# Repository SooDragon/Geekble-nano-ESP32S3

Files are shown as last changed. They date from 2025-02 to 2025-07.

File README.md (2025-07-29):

Geekble nano ESP32-S3
=============
Geekble nano ESP32-S3 문서에 오신것을 환영합니다

아두이노 IDE에서 쉽게 사용할 수 있는 Geekble nano를 통해 WiFi, Bluetooth, USB HID 기능을 여러분의 프로젝트에 구현할 수 있습니다

Geekble nano 핀맵
-------------
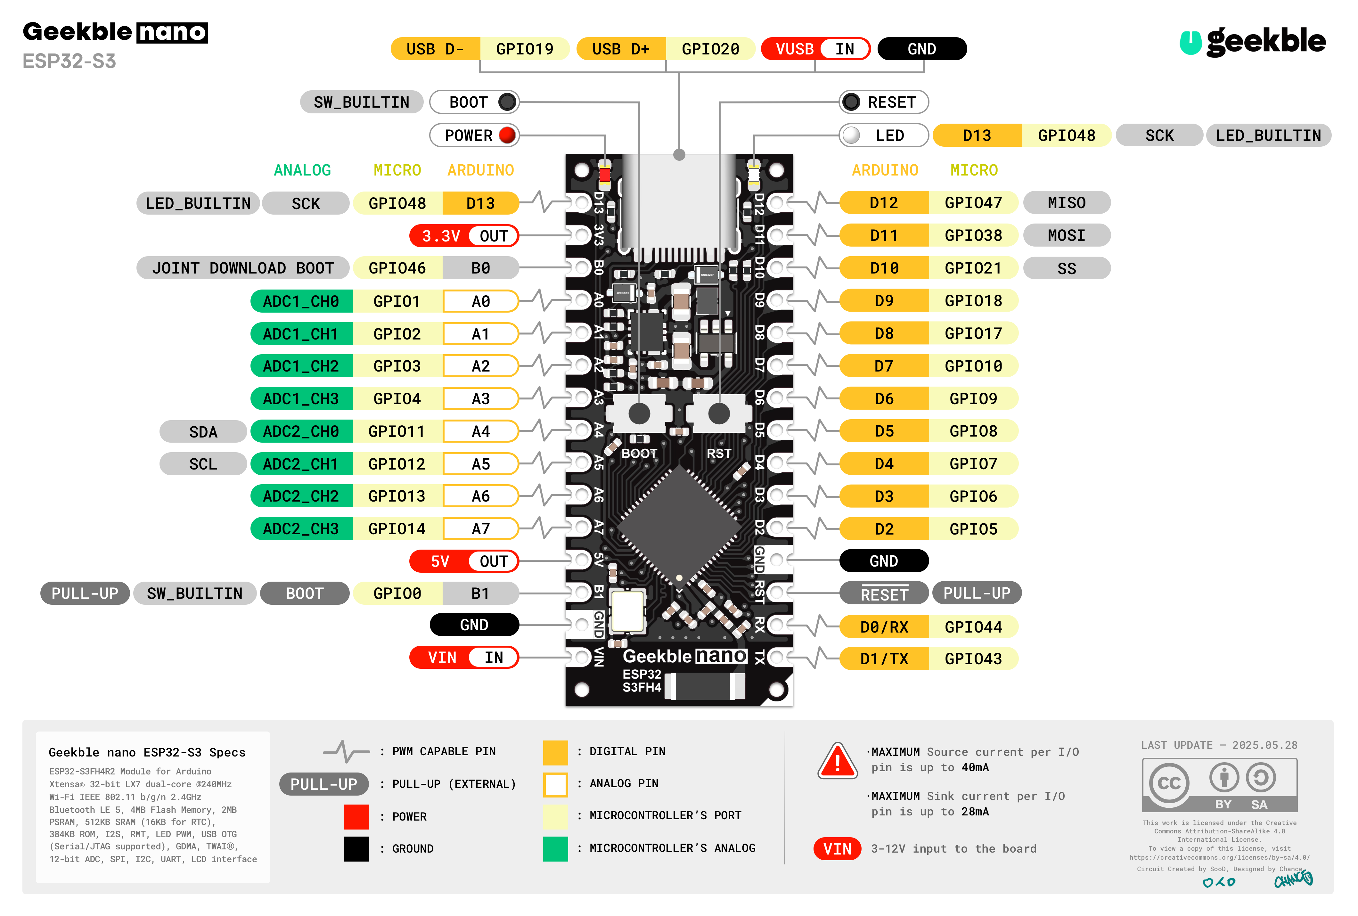
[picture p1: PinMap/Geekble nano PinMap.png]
GEEKBLE nano ESP32-S3

Geekble nano PinMap

Geekble nano 회로도
-------------
Geekble nano Schematic
Geekble nano Schematic

Geekble nano 치수도
-------------
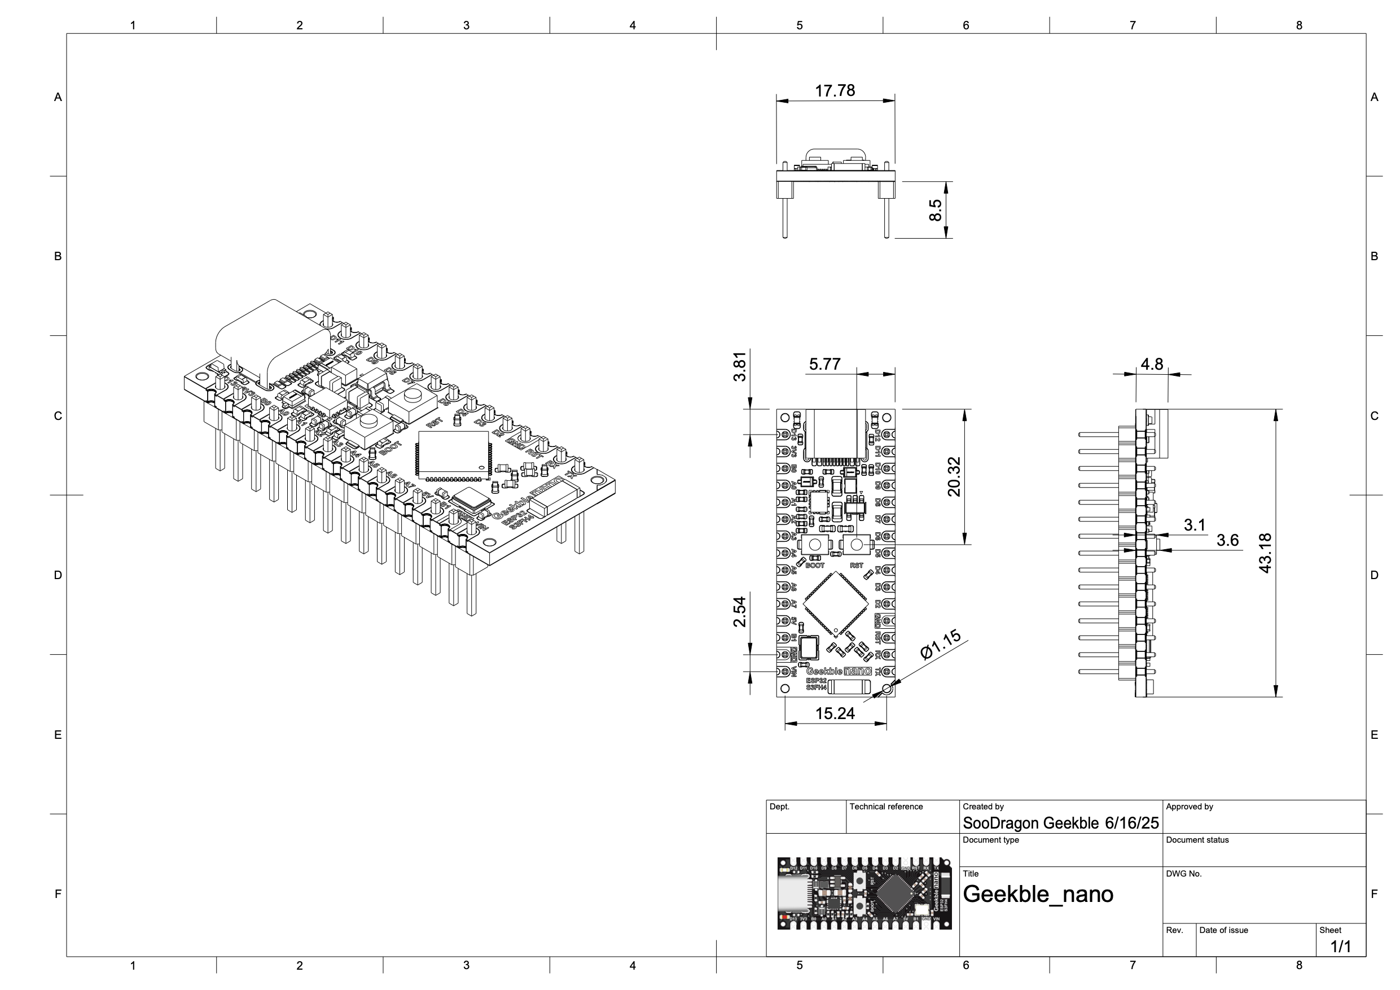
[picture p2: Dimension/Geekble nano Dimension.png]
Dimension

Geekble nano Dimension

Geekble nano Version Log
-------------
- Ver.1.0: 최초 공개 버전
- Ver.2.0: 3.3V Buck-Boost 회로에서 5V Buck-Boost + 3.3V 리니어 레귤레이터 구조로 변경
- Ver.2.2: 안테나 임피던스 매칭용 커페시터 C1, C2 값을 1.8pF에서 1.5pF으로 변경
- Ver.2.3: 안테나 임피던스 매칭용 커페시터 C1 값을 2pF으로, C2 값을 1pF으로 변경
- Ver.2.4:안테나 임피던스 매칭용 커페시터 C1 값을 1pF으로, C2 값을 2pF으로 변경
- Ver.2.5: 안테나 임피던스 매칭용 커페시터 C1 값을 1pF에서 1.2pF으로 변경

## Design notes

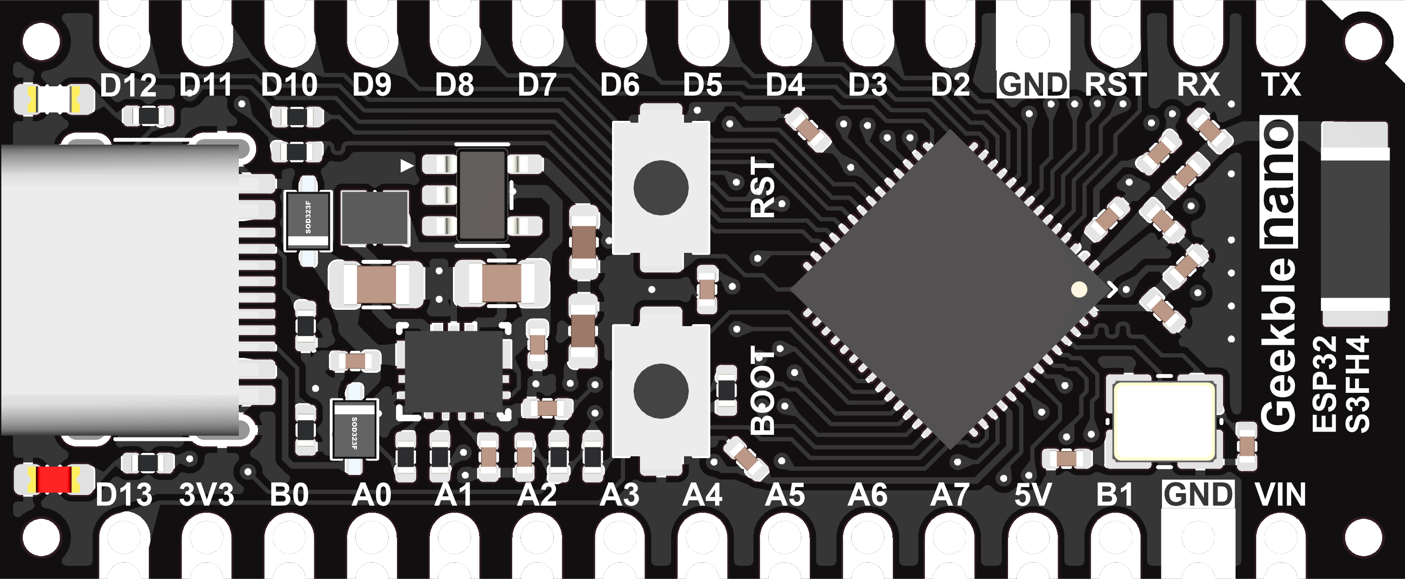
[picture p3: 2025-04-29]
Image/Geekble_nano_TopView.png

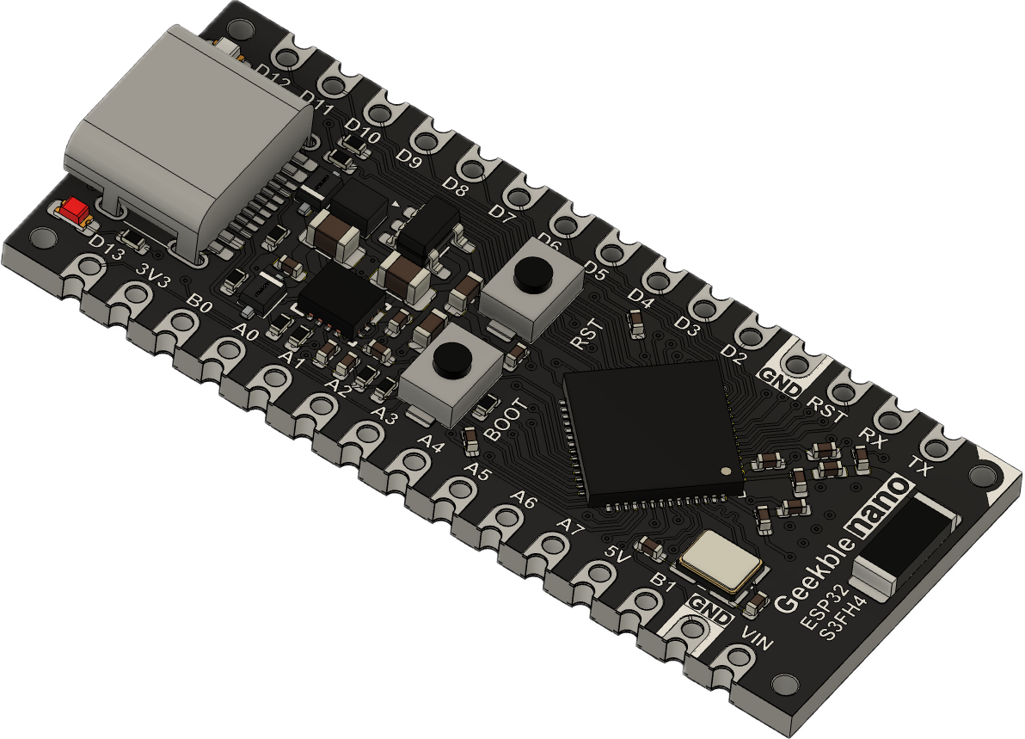
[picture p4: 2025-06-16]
Image/Geeble nano shape.png

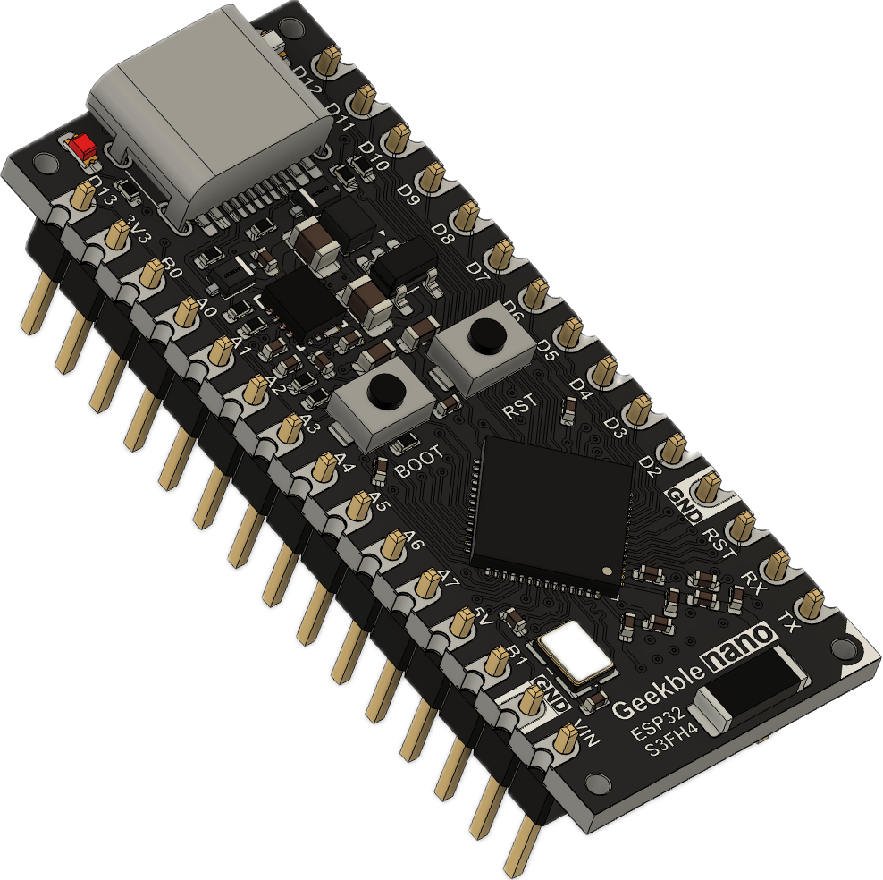
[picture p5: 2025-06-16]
Image/Geeble nano shape PinHeader.png

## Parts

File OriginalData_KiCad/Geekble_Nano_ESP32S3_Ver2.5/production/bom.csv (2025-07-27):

Designator | Footprint | Quantity | Value | LCSC Part #
ANT1 | ANT_5020 | 1 | KH-5020D245H05 | C45359218
C1 | C_0402 | 1 | 1.2pF,50V | C327292
C10, C7, C8 | C_0402 | 3 | 1uF,25V | C52923
C11 | C_0402 | 1 | 10nF,50V | C15195
C12, C13 | C_0402 | 2 | 15pF,50V | C1548
C14, C16, C3, C5, C9 | C_0402 | 5 | 100nF,50V | C307331
C15, C4 | C_0402 | 2 | 10uF,10V | C386033
C17 | C_0805 | 1 | 47uF,10V,0805 | C124129
C18, C19 | C_0603 | 2 | 22uF,6.3V,0603 | C59461
C2 | C_0402 | 1 | 2pF,50V | C281756
C6 | C_0805 | 1 | 22uF,25V,0805 | C45783
D1, D2 | SOD-323F | 2 | 1N5819WS | C191023
H1, H2, H20, H21, H22, H23, H24, H3, H4, H40, H41, H42, H43, H44 | 1x1_1.0piPad_SMD | 14 | MountingHole_Pad
H10, H11, H12, H13, H14, H15, H16, H17, H18, H19, H25, H26, H27, H28, H29, H30, H31, H32, H33, H34, H35, H36, H37, H38, H39, H5, H6, H7, H8, H9 | 1x1_P2.54_CastellatedPad | 30 | MountingHole_Pad
J1 | USB_DIP,8.94x7.3mm | 1 | USB_C_Receptacle_USB2.0_DIP | C165948
L1, L2 | L_0402 | 2 | 2.7nH,800mA,120mR | C77108
L3 | FTC201612S | 1 | 1.5uH,4A,40mR | C5832350
LED1 | LED_0603_Red | 1 | LED,0603,Red | C2286
LED2 | LED_0603_White | 1 | LED,0603,White | C2290
LOGO1 | SooDragonKOR_Mask_3.8x1.4 | 1 | Geekble_Logo
R1, R2, R7 | R_0402 | 3 | 10KR,1% | C25744
R10, R3, R4, R9 | R_0402 | 4 | 5.1KR,1% | C25905
R11 | R_0402 | 1 | 499R,1% | C4125
R5, R6 | R_0402 | 2 | 33R,1% | C25105
R8 | R_0402 | 1 | 100KR,1% | C25741
SW1, SW2 | TS-1088-AR020 | 2 | TS-1088-AR02016 | C720477
TH1, TH2, TH3, TH4 | ToolingHole_JLCPCB | 4 | ToolingHole
U1 | RNM0015A | 1 | TPS630701RNMR | C2876599
U2 | QFN-56-1EP_7x7mm_P0.4mm_EP5.6x5.6mm | 1 | ESP32-S3FH4R2 | C3013940
U3 | SOT-23-5 | 1 | ME6217C33M5G | C427602
Y1 | SMD-3225_4P | 1 | 40MHz | C9010

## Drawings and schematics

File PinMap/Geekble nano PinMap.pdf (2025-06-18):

## Geekble Mini

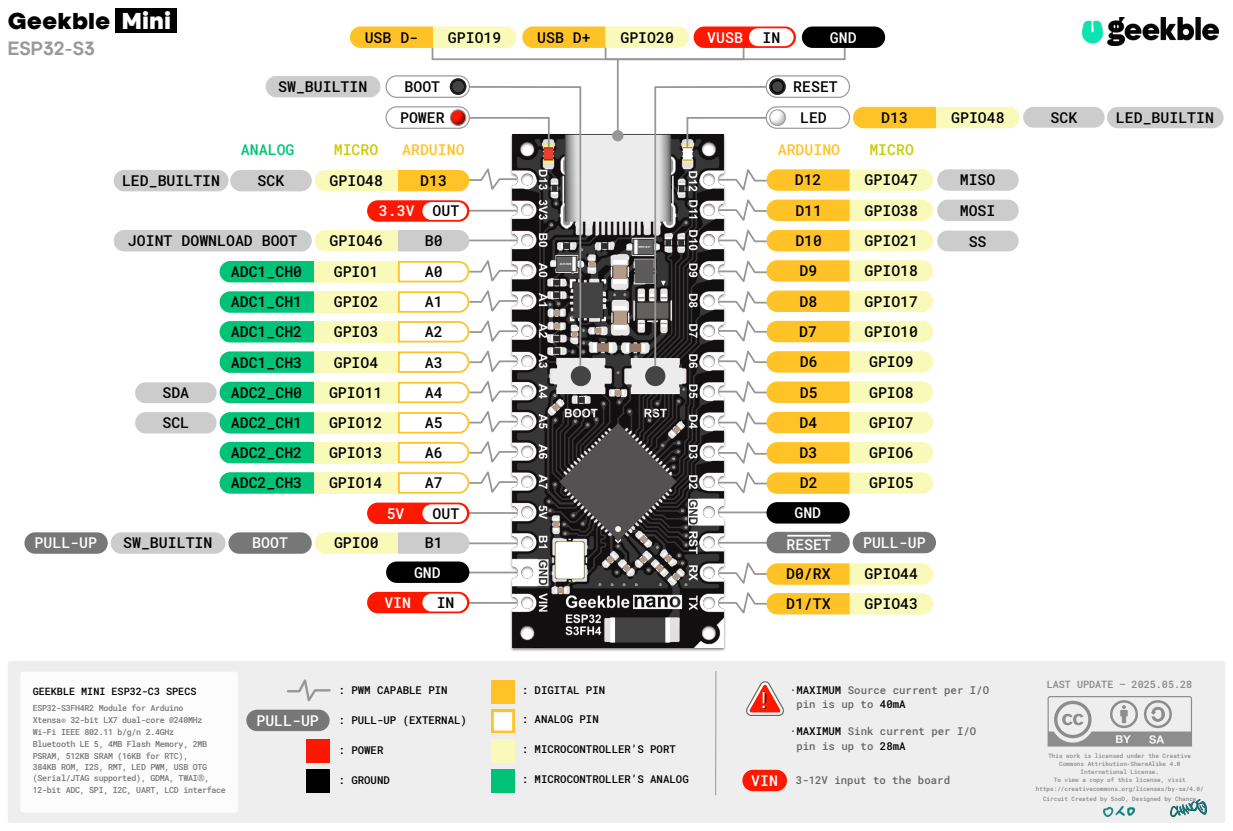
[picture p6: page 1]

·MAXIMUM Source current per I/O
pin is up to 40mA
·MAXIMUM Sink current per I/O
pin is up to 28mA

GEEKBLE MINI ESP32-C3 SPECS
ESP32-S3FH4R2 Module for Arduino
Xtensa® 32-bit LX7 dual-core @240MHz
Wi-Fi IEEE 802.11 b/g/n 2.4GHz
Bluetooth LE 5, 4MB Flash Memory, 2MB
PSRAM, 512KB SRAM (16KB for RTC),
384KB ROM, I2S, RMT, LED PWM, USB OTG
(Serial/JTAG supported), GDMA, TWAIⓇ,
12-bit ADC, SPI, I2C, UART, LCD interface

This work is licensed under the Creative
Commons Attribution-ShareAlike 4.0
International License.

VIN 3-12V input to the board

To view a copy of this license, visit
https://creativecommons.org/licenses/by-sa/4.0/
Circuit Created by SooD, Designed by Chance

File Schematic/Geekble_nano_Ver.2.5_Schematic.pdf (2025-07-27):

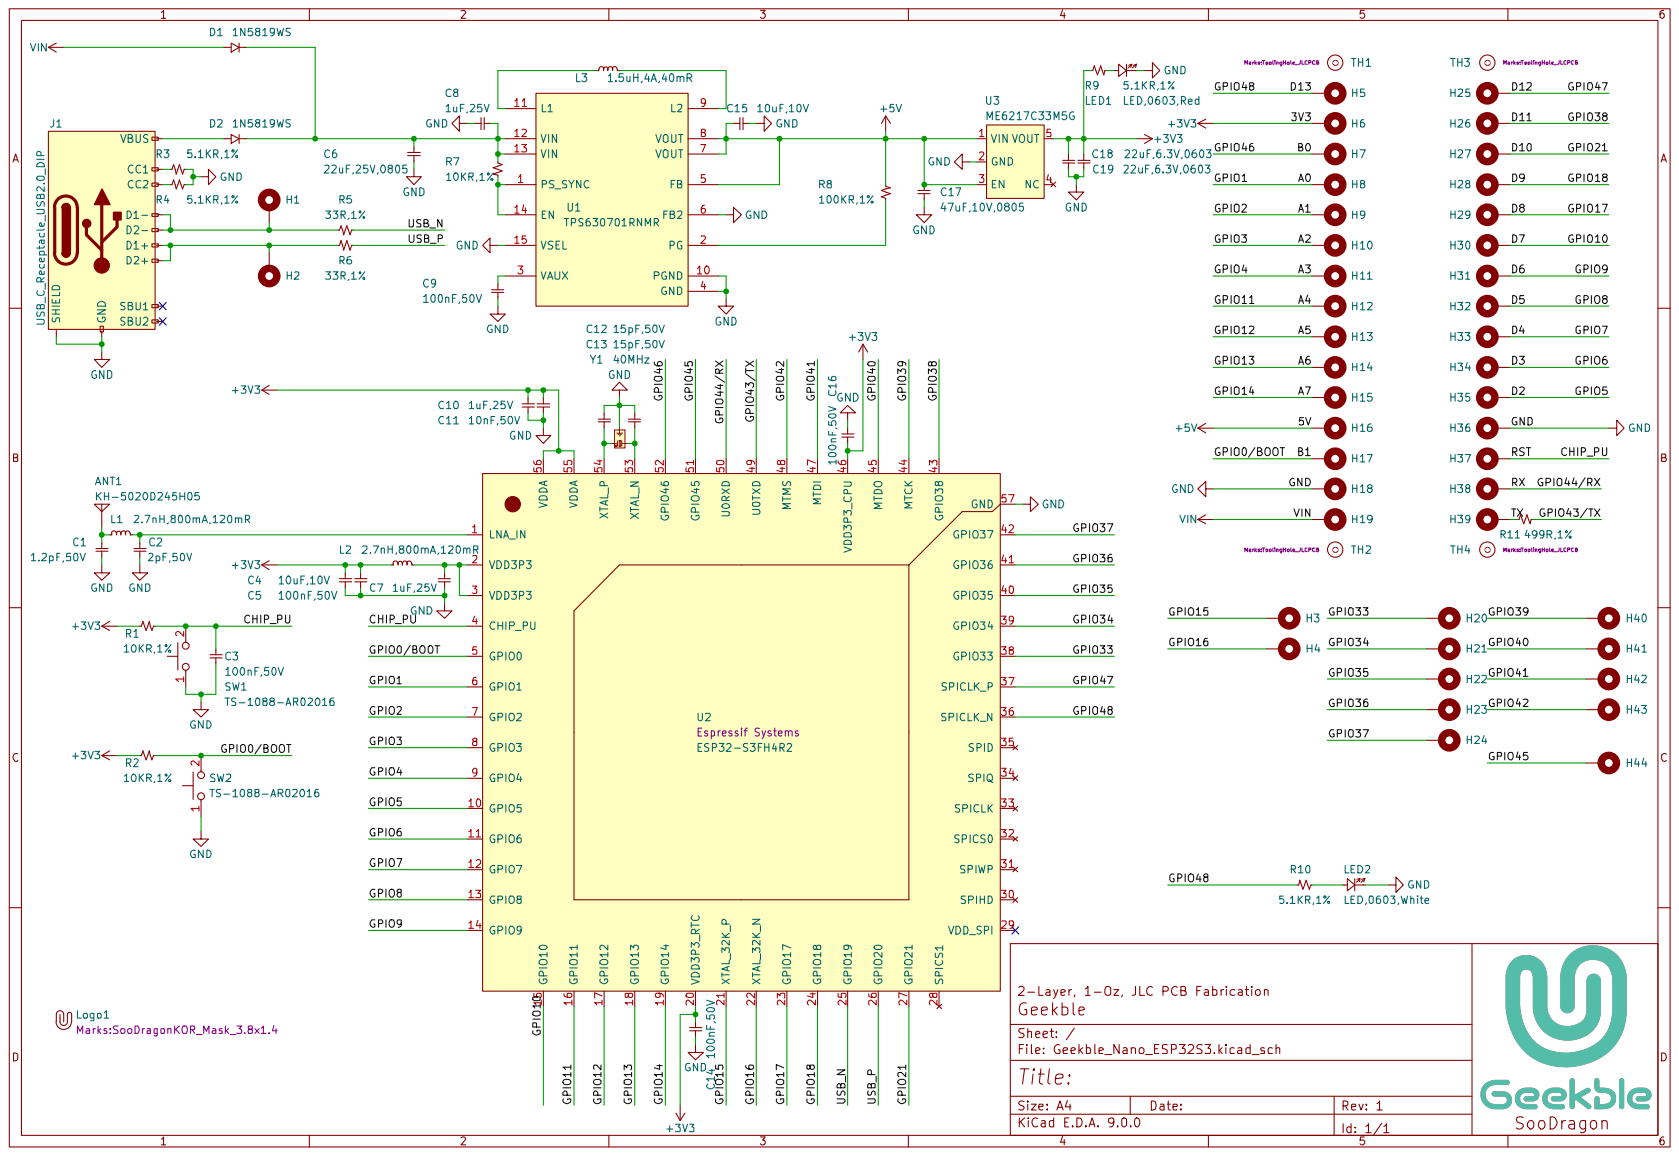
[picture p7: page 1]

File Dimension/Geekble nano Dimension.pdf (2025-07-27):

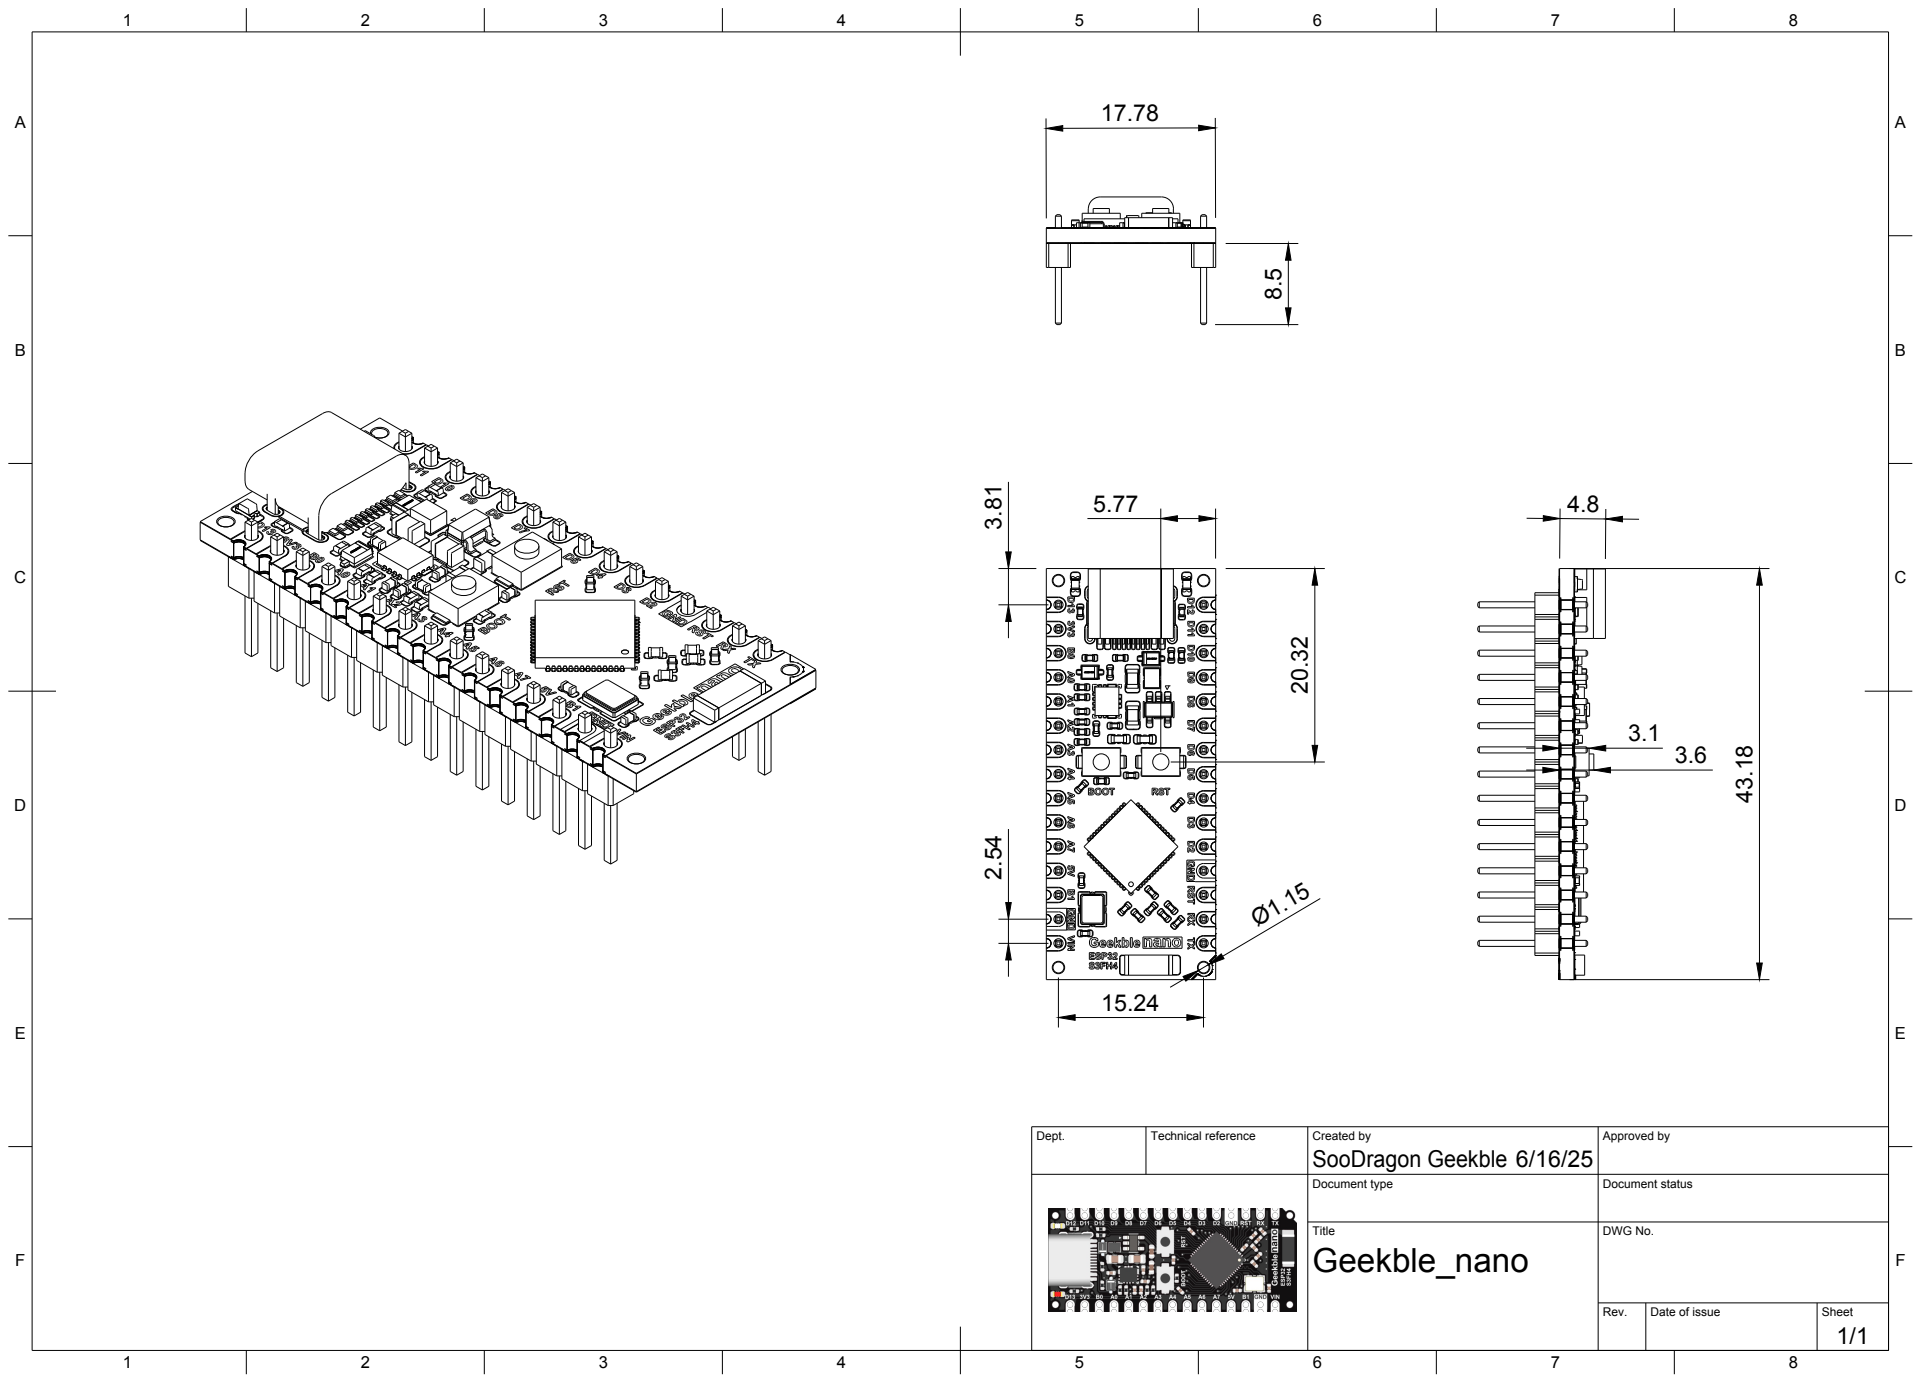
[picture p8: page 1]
Dept.; Technical reference; Created by; Approved by; Document type; Document status; Title; DWG No.; Rev.; Date of issue; Sheet; SooDragon Geekble

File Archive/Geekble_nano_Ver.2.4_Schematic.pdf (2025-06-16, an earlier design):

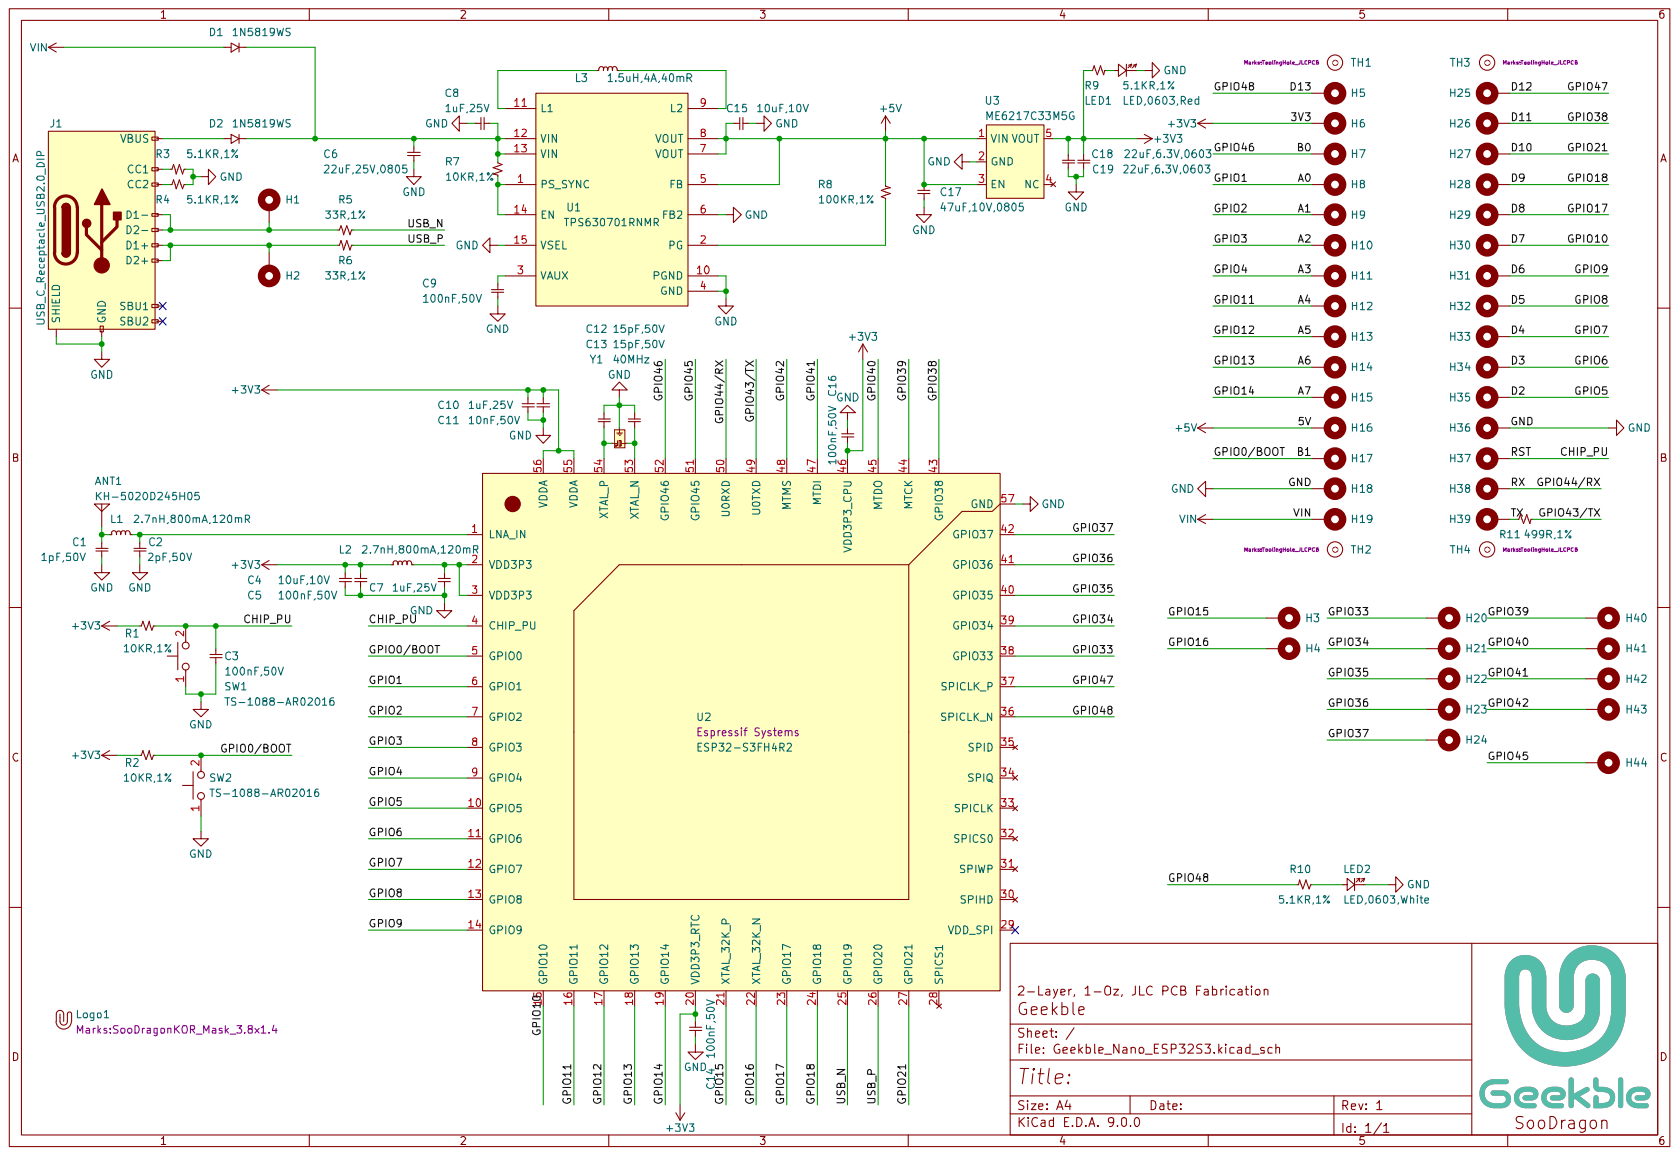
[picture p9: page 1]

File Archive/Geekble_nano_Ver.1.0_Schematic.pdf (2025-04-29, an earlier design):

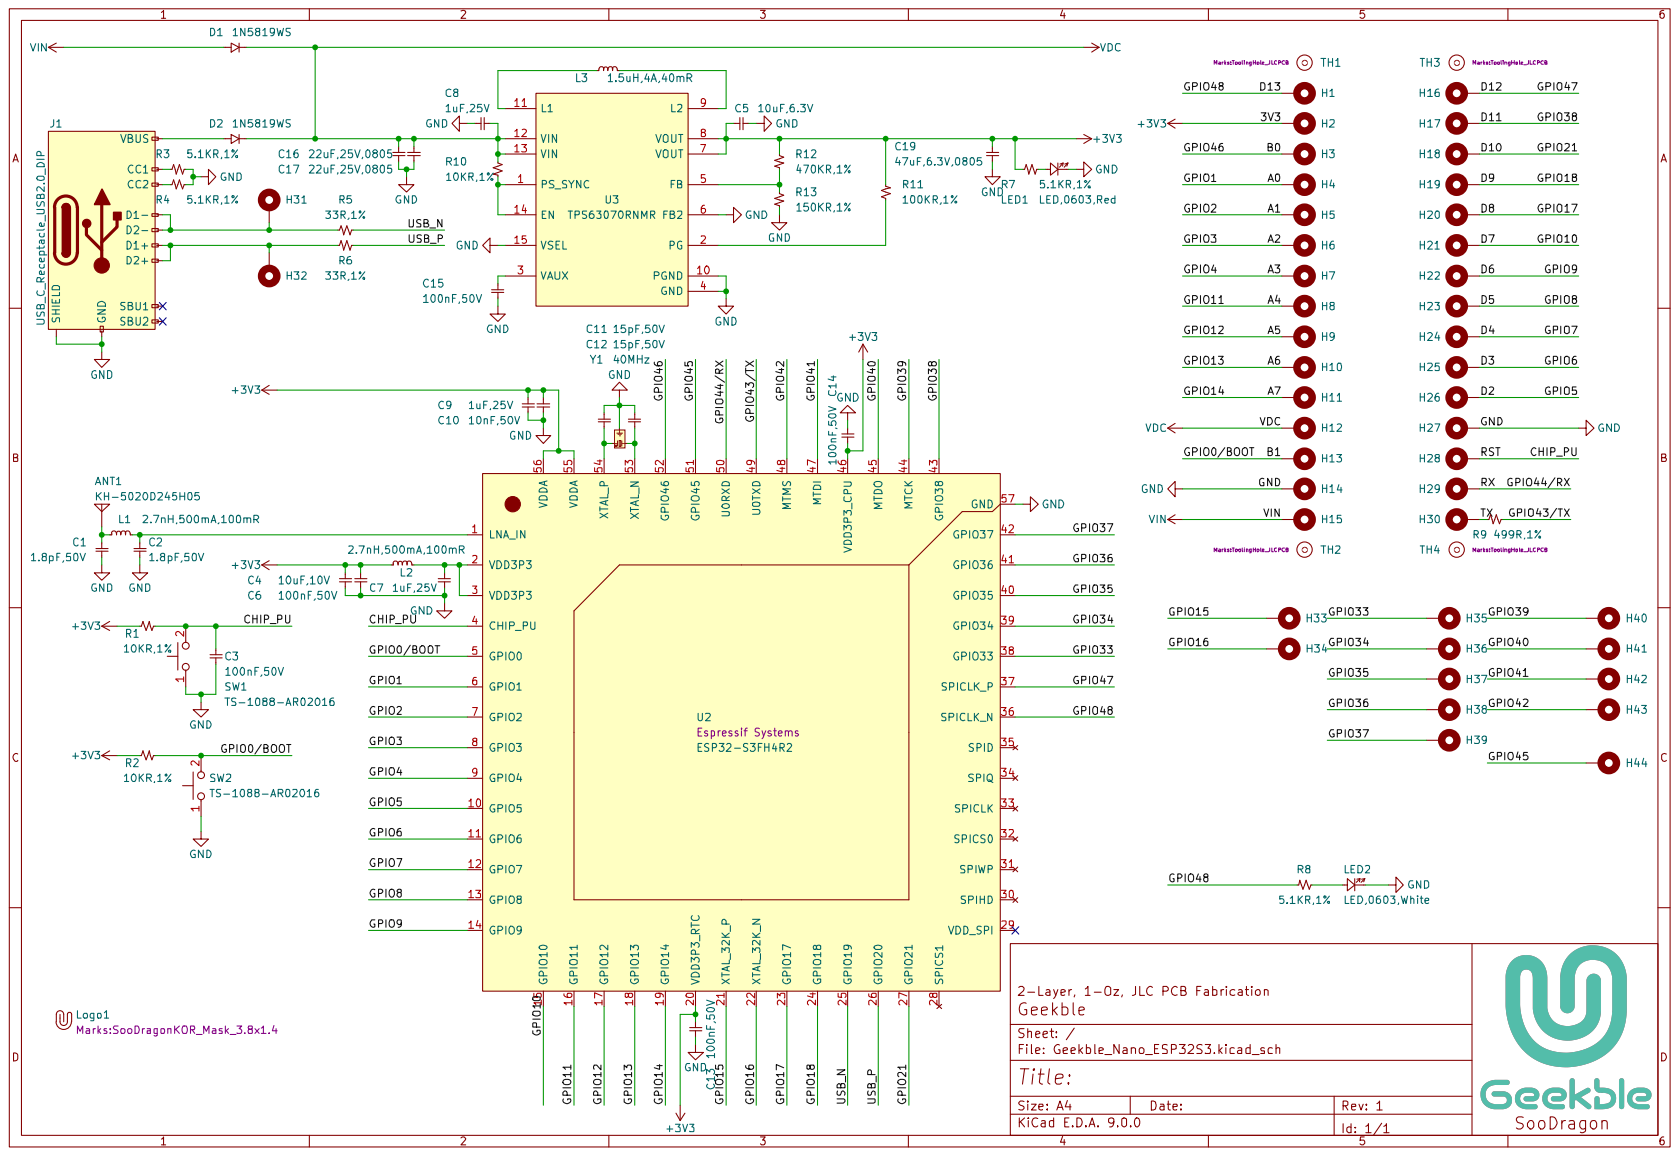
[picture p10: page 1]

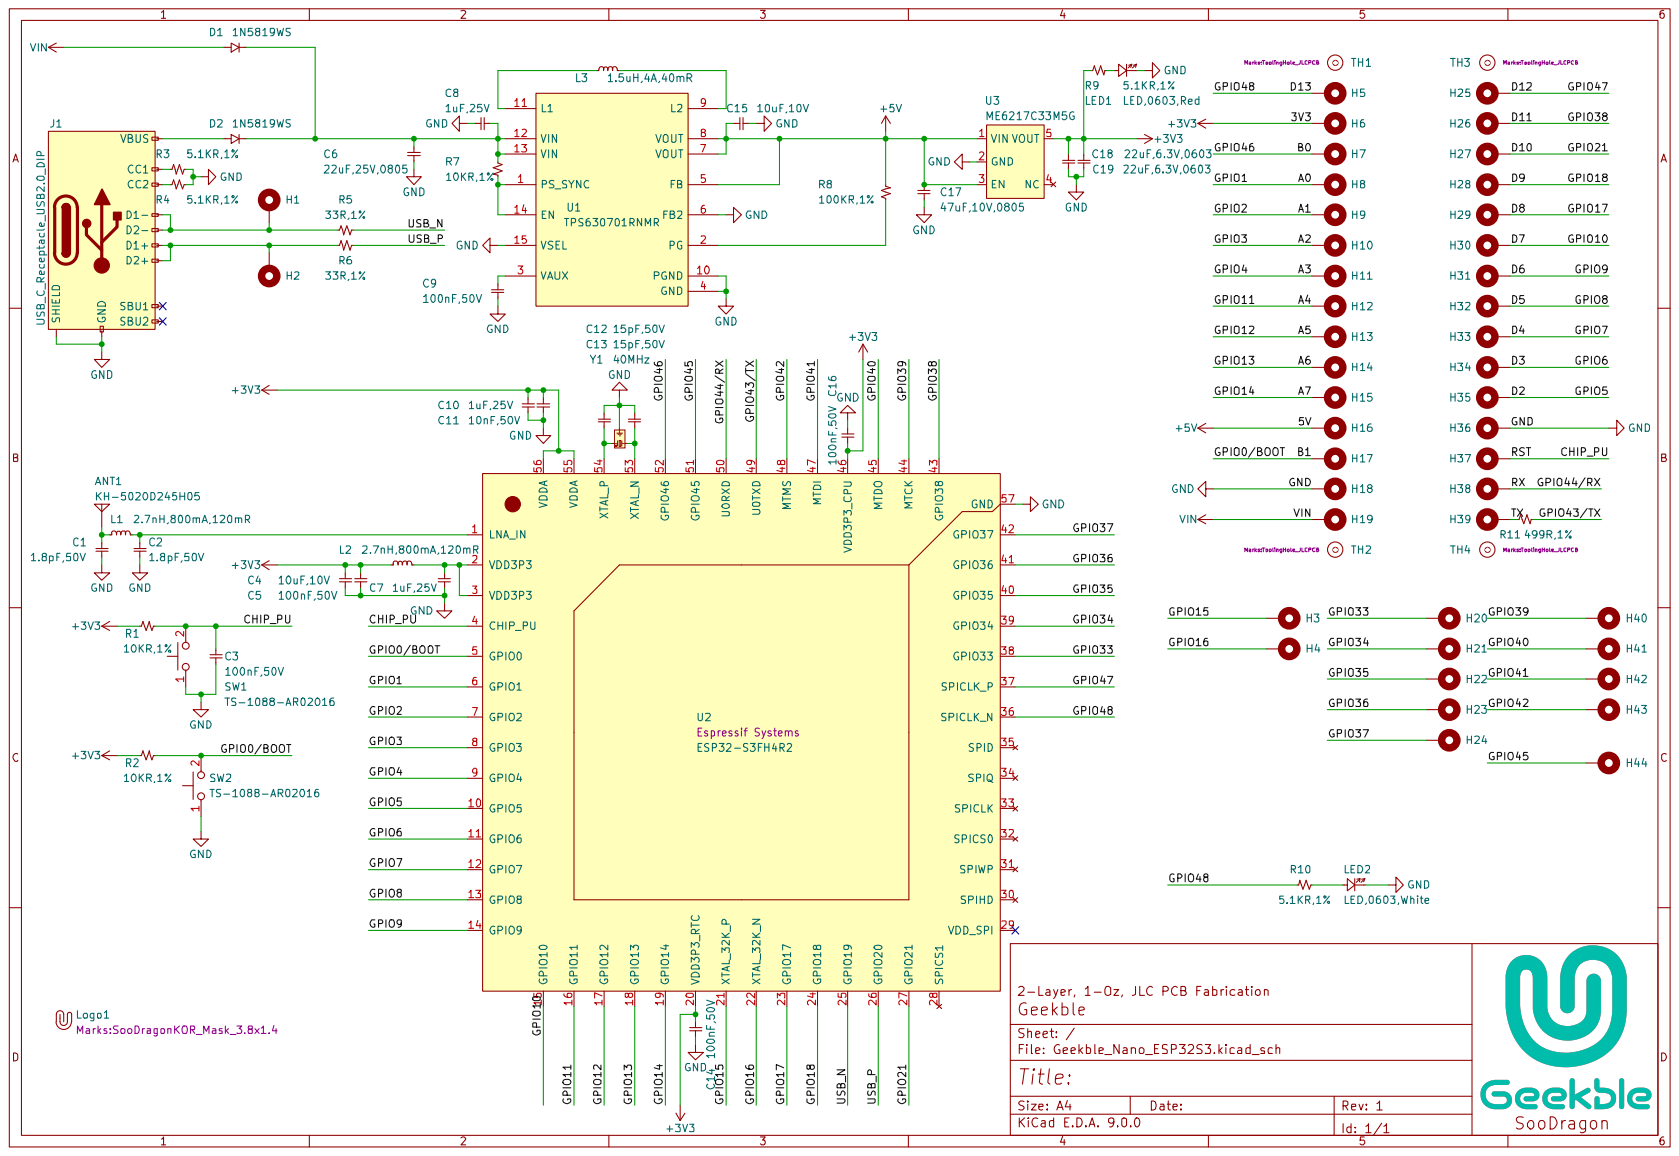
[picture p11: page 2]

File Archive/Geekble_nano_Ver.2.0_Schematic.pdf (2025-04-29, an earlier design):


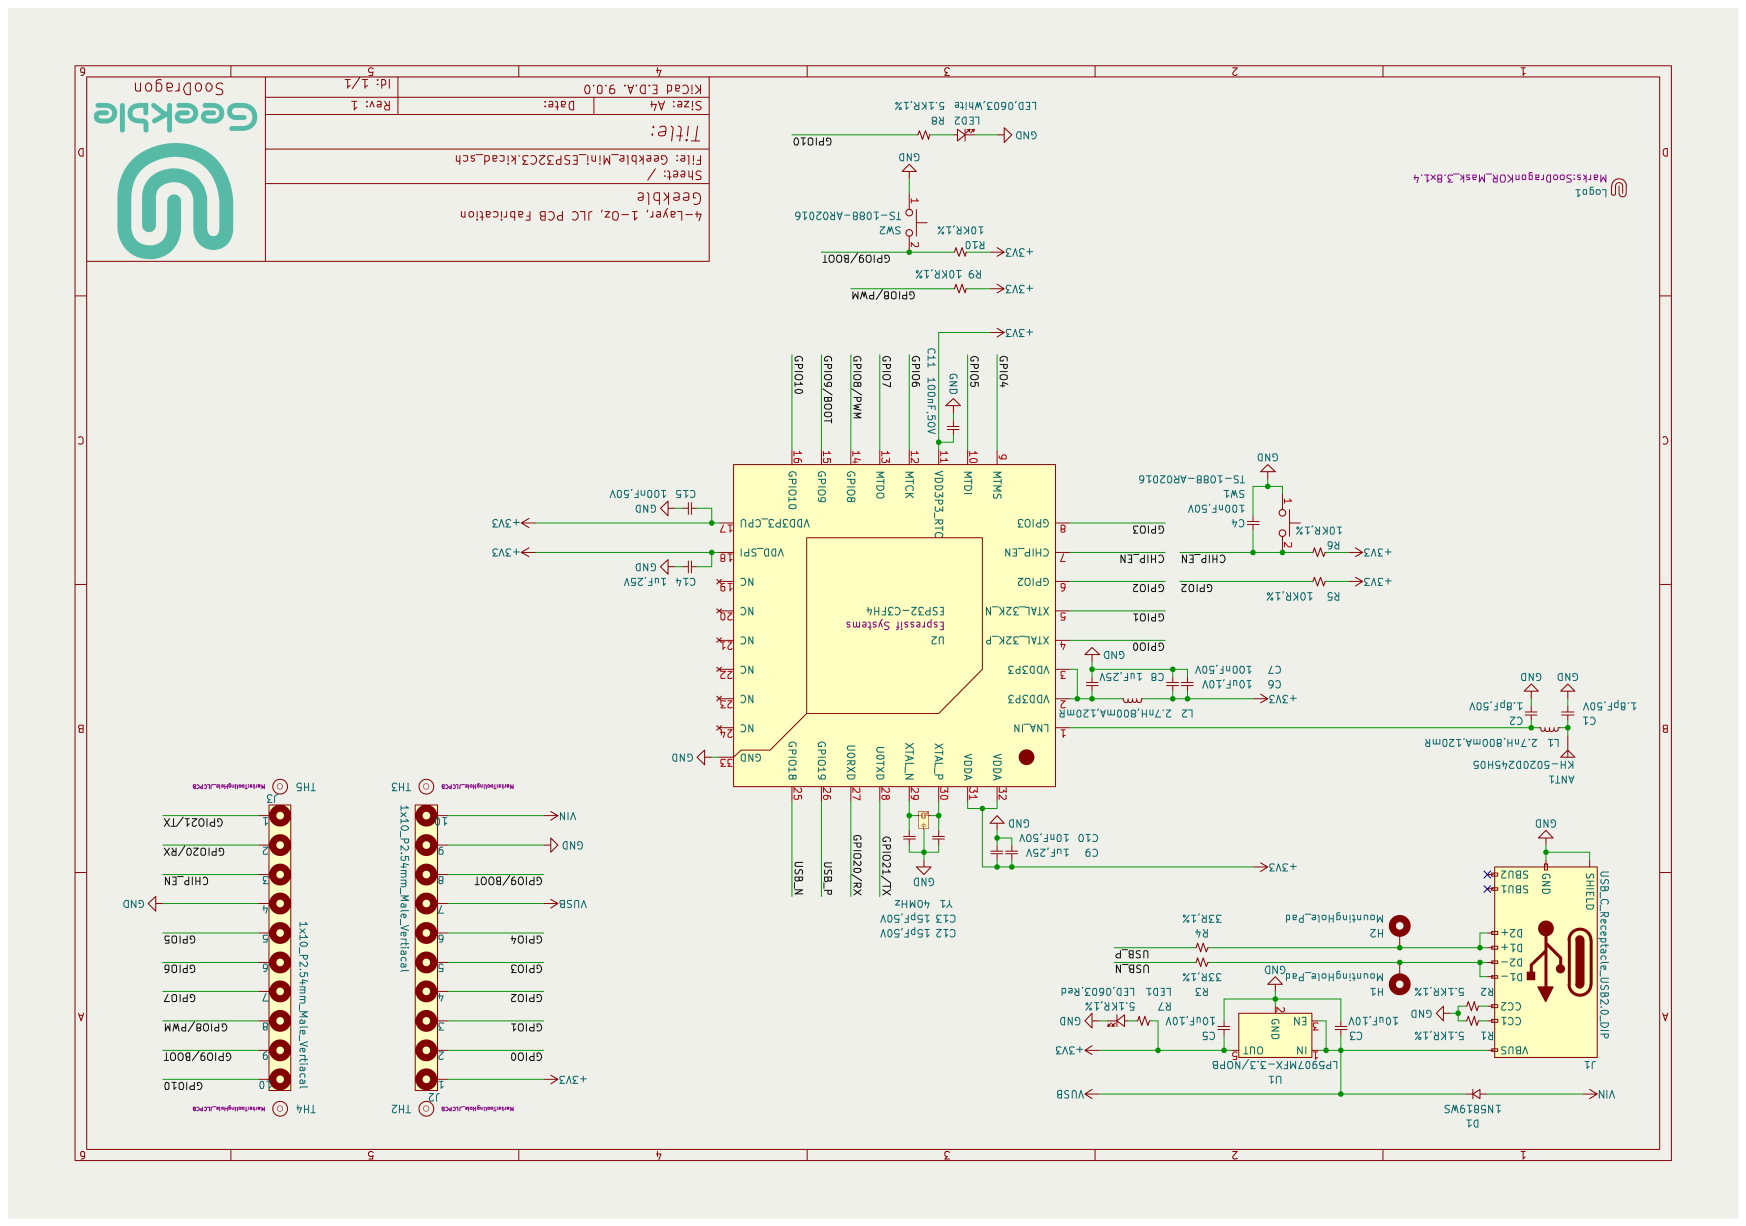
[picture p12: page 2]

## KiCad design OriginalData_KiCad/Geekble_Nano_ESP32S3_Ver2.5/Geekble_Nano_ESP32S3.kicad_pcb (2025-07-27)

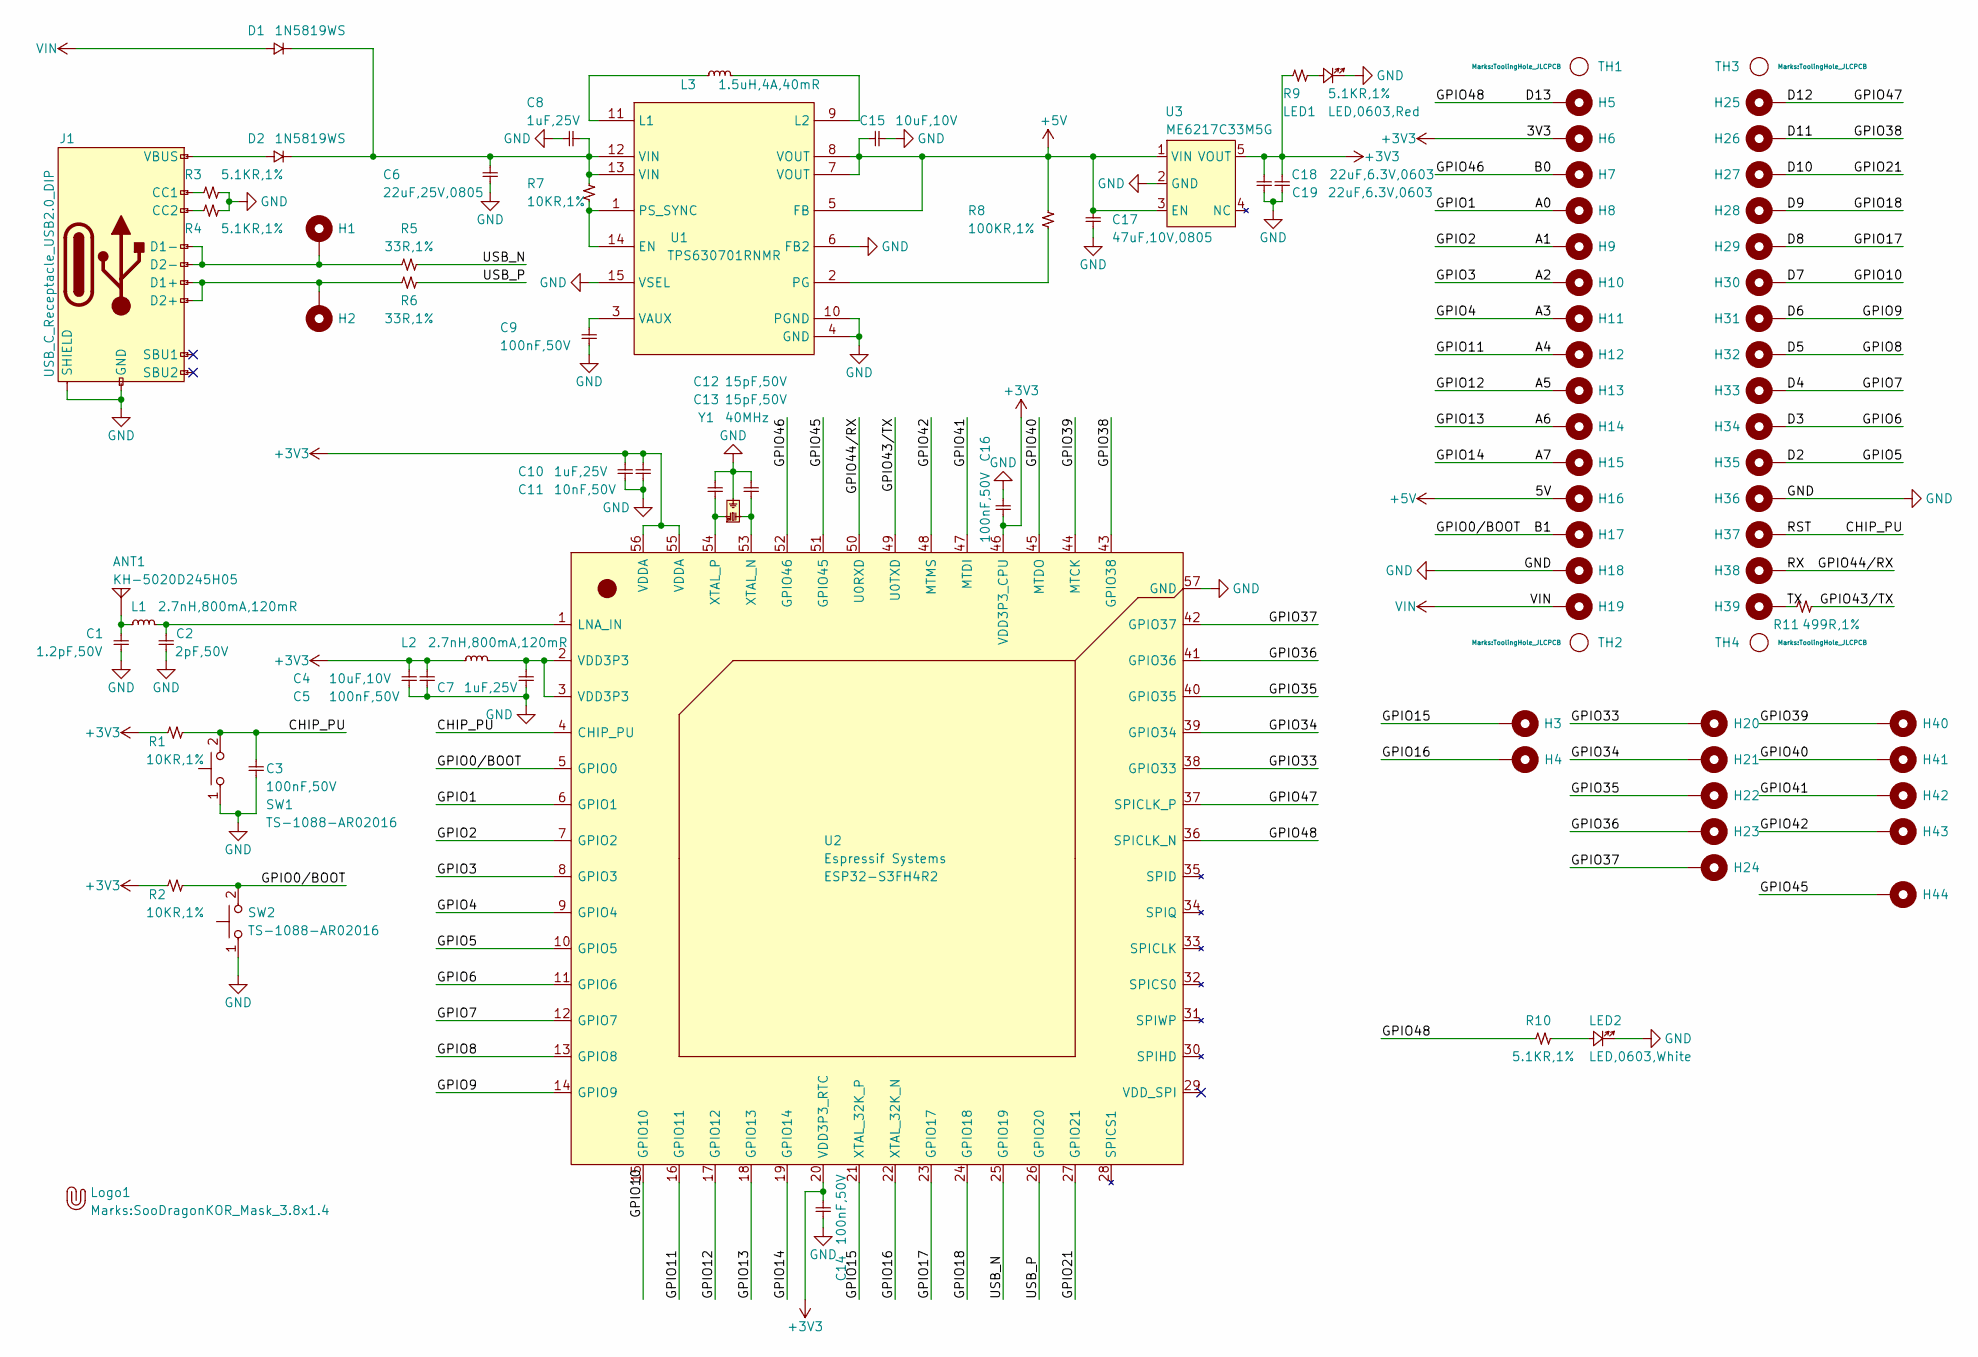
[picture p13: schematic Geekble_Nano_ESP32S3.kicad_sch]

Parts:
ANT1: KH-5020D245H05; ANT_5020; Manufacturer Part Number KH-5020D245H05; LCSC C45359218
C1: 1.2pF,50V; C_0402; Manufacturer Part Number CC0402BRNPO9BN1R2; LCSC C327292
C2: 2pF,50V; C_0402; Manufacturer Part Number CC0402BRNPO9BN2R0; LCSC C281756
C3, C5, C9, C14, C16: 100nF,50V; C_0402; Manufacturer Part Number CL05B104KB54PNC; LCSC C307331
C4, C15: 10uF,10V; C_0402; Manufacturer Part Number LDK105CBJ106MVLF; LCSC C386033
C6: 22uF,25V,0805; C_0805; Manufacturer Part Number CL21A226MAQNNNE; LCSC C45783
C7, C8, C10: 1uF,25V; C_0402; Manufacturer Part Number CL05A105KA5NQNC; LCSC C52923
C11: 10nF,50V; C_0402; Manufacturer Part Number CL05B103KB5NNNC; LCSC C15195
C12, C13: 15pF,50V; C_0402; Manufacturer Part Number 0402CG150J500NT; LCSC C1548
C17: 47uF,10V,0805; C_0805; Manufacturer Part Number GRM21BR61A476ME15L; LCSC C124129
C18, C19: 22uF,6.3V,0603; C_0603; Manufacturer Part Number CL10A226MQ8NRNC; LCSC C59461
D1, D2: 1N5819WS; SOD-323F; Manufacturer Part Number 1N5819WS; LCSC C191023
H1, H2, H3, H4, H20, H21, H22, H23, H24, H40, H41, H42, H43, H44: MountingHole_Pad; 1x1_1.0piPad_SMD
H5, H6, H7, H8, H9, H10, H11, H12, H13, H14, H15, H16, H17, H18, H19, H25, H26, H27, H28, H29, H30, H31, H32, H33, H34, H35, H36, H37, H38, H39: MountingHole_Pad; 1x1_P2.54_CastellatedPad
J1: USB_C_Receptacle_USB2.0_DIP; USB_DIP,8.94x7.3mm; Manufacturer Part Number TYPE-C-31-M-12; LCSC C165948
L1, L2: 2.7nH,800mA,120mR; L_0402; Manufacturer Part Number LQG15HS2N7S02D; LCSC C77108
L3: 1.5uH,4A,40mR; FTC201612S; Manufacturer Part Number FTC201612S1R5MBCA; LCSC C5832350
LED1: LED,0603,Red; LED_0603_Red; Manufacturer Part Number KT-0603R; LCSC C2286
LED2: LED,0603,White; LED_0603_White; LCSC C2290
Logo1: Geekble_Logo; SooDragonKOR_Mask_3.8x1.4
R1, R2, R7: 10KR,1%; R_0402; Manufacturer Part Number 0402WGF1002TCE; LCSC C25744
R3, R4, R9, R10: 5.1KR,1%; R_0402; Manufacturer Part Number 0402WGF5101TCE; LCSC C25905
R5, R6: 33R,1%; R_0402; Manufacturer Part Number 0402WGF330JTCE; LCSC C25105
R8: 100KR,1%; R_0402; Manufacturer Part Number 0402WGF1003TCE; LCSC C25741
R11: 499R,1%; R_0402; Manufacturer Part Number 0402WGF4990TCE; LCSC C4125
SW1, SW2: TS-1088-AR02016; TS-1088-AR020; Manufacturer Part Number TS-1088-AR02016; LCSC C720477
TH1, TH2, TH3, TH4: ToolingHole; ToolingHole_JLCPCB
U1: TPS630701RNMR; RNM0015A; Manufacturer Part Number TPS630701RNMR; LCSC C2876599
U2: ESP32-S3FH4R2; QFN-56-1EP_7x7mm_P0.4mm_EP5.6x5.6mm; Manufacturer Part Number ESP32-S3FH4R2; LCSC C3013940
U3: ME6217C33M5G; SOT-23-5; Manufacturer Part Number ME6217C33M5G; LCSC C427602
Y1: 40MHz; SMD-3225_4P; Manufacturer Part Number X322540MPB4SI; LCSC C9010

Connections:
+3V3: C4.2, C5.2, C10.2, C11.2, C14.2, C16.2, C18.2, C19.2, H6.1, L2.1, R1.1, R2.1, R9.1, U2.20 (VDD3P3_RTC), U2.46 (VDD3P3_CPU), U2.55 (VDDA), U2.56 (VDDA), U3.5 (VOUT)
+5V: C15.2, C17.2, H16.1, R8.2, U1.5 (FB), U1.7 (VOUT), U1.8 (VOUT), U3.1 (VIN), U3.3 (EN)
/A0: H8.1, U2.6 (GPIO1)
/A1: H9.1, U2.7 (GPIO2)
/A2: H10.1, U2.8 (GPIO3)
/A3: H11.1, U2.9 (GPIO4)
/A4: H12.1, U2.16 (GPIO11)
/A5: H13.1, U2.17 (GPIO12)
/A6: H14.1, U2.18 (GPIO13)
/A7: H15.1, U2.19 (GPIO14)
/B0: H7.1, U2.52 (GPIO46)
/B1: H17.1, R2.2, SW2.2 (B), U2.5 (GPIO0)
/CHIP_PU: C3.2, H37.1, R1.2, SW1.2 (B), U2.4 (CHIP_PU)
/D2: H35.1, U2.10 (GPIO5)
/D3: H34.1, U2.11 (GPIO6)
/D4: H33.1, U2.12 (GPIO7)
/D5: H32.1, U2.13 (GPIO8)
/D6: H31.1, U2.14 (GPIO9)
/D7: H30.1, U2.15 (GPIO10)
/D8: H29.1, U2.23 (GPIO17)
/D9: H28.1, U2.24 (GPIO18)
/D10: H27.1, U2.27 (GPIO21)
/D11: H26.1, U2.43 (GPIO38)
/D12: H25.1, U2.37 (SPICLK_P)
/D13: H5.1, R10.2, U2.36 (SPICLK_N)
/GPIO15: H3.1, U2.21 (XTAL_32K_P)
/GPIO16: H4.1, U2.22 (XTAL_32K_N)
/GPIO33: H20.1, U2.38 (GPIO33)
/GPIO34: H21.1, U2.39 (GPIO34)
/GPIO35: H22.1, U2.40 (GPIO35)
/GPIO36: H23.1, U2.41 (GPIO36)
/GPIO37: H24.1, U2.42 (GPIO37)
/GPIO39: H40.1, U2.44 (MTCK)
/GPIO40: H41.1, U2.45 (MTDO)
/GPIO41: H42.1, U2.47 (MTDI)
/GPIO42: H43.1, U2.48 (MTMS)
/GPIO43/TX: R11.1, U2.49 (U0TXD)
/GPIO44/RX: H38.1, U2.50 (U0RXD)
/GPIO45: H44.1, U2.51 (GPIO45)
/TX: H39.1, R11.2
/USB_N: R5.2, U2.25 (GPIO19)
/USB_P: R6.2, U2.26 (GPIO20)
GND: C1.1, C2.1, C3.1, C4.1, C5.1, C6.1, C7.1, C8.1, C9.1, C10.1, C11.1, C12.1, C13.1, C14.1, C15.1, C16.1, C17.1, C18.1, C19.1, H18.1, H36.1, J1.A1B12 (GND), J1.B1A12 (GND), J1.S1 (SHIELD), J1.S2 (SHIELD), J1.S3 (SHIELD), J1.S4 (SHIELD), LED1.C, LED2.C, R3.2, R4.2, SW1.1 (A), SW2.1 (A), U1.4 (GND), U1.6 (FB2), U1.10 (PGND), U1.15 (VSEL), U2.57 (GND), U3.2 (GND), Y1.2 (GND), Y1.4 (GND)
unnamed: ANT1.Feed, C1.2, L1.1
unnamed: C6.2, C8.2, D1.C, D2.C, R7.2, U1.12 (VIN), U1.13 (VIN)
unnamed: C7.2, L2.2, U2.2 (VDD3P3), U2.3 (VDD3P3)
unnamed: D2.A, J1.A4B9 (VBUS), J1.B4A9 (VBUS)
unnamed: J1.A5 (CC1), R3.1
unnamed: J1.B5 (CC2), R4.1
unnamed: H2.1, J1.A6 (D1+), J1.B6 (D2+), R6.1
unnamed: H1.1, J1.A7 (D1-), J1.B7 (D2-), R5.1
unnamed: LED1.A, R9.2
unnamed: LED2.A, R10.1
unnamed: R7.1, U1.1 (PS_SYNC), U1.14 (EN)
unnamed: L3.1, U1.11 (L1)
unnamed: L3.2, U1.9 (L2)
unnamed: R8.1, U1.2 (PG)
unnamed: C9.2, U1.3 (VAUX)
unnamed: C2.2, L1.2, U2.1 (LNA_IN)
unnamed: C13.2, U2.53 (XTAL_N), Y1.3 (OSC2)
unnamed: C12.2, U2.54 (XTAL_P), Y1.1 (OSC1)
VIN: D1.A, H19.1

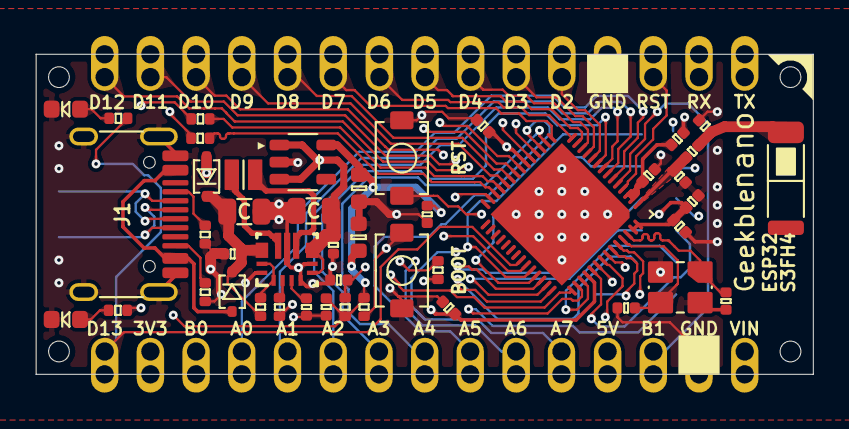
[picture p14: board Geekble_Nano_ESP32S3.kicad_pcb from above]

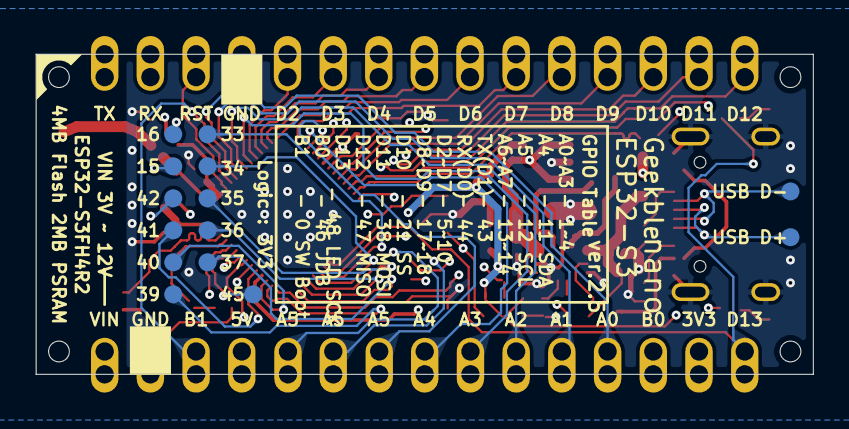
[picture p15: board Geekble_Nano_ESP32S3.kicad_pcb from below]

Board: 4 copper layers, 43.2 x 17.8 mm, 94 parts (14 on the bottom side), 62 nets.

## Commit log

2025-02-23 1.0
    1.0 data
    [Geekble_Nano_ESP32S3.kicad_pcb, Geekble_Nano_ESP32S3.kicad_sch, bom.csv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]
2025-03-03 2.0
    2.0
    [Geekble_Nano_ESP32S3.kicad_pcb, Geekble_Nano_ESP32S3.kicad_sch, bom.csv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]
2025-06-16 ud
    ud
    [Geekble_Nano_ESP32S3.kicad_pcb, Geekble_Nano_ESP32S3.kicad_sch, bom.csv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]
2025-07-27 Ver.2.5
    Ver.2.5
    [Geekble_Nano_ESP32S3.kicad_pcb, Geekble_Nano_ESP32S3.kicad_sch, bom.csv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]
